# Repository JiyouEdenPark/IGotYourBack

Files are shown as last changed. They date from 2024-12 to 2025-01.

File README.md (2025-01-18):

# IGotYourBack

A mechanical recreation of a childhood game – where friends would write messages on your back and you had to focus on the feeling to get it right.

## Project Showcase
Project Demo (https://www.youtube.com/watch?v=ZsXyqrq_RdM)

## Description
In this day and age where we are inundated by ubiquitous and instantaneous communication, we invite you to an experience where you communicate with others word by word, one letter at a time. As the user gauges how keenly they can decipher a tactile message, it symbolizes how even the smallest units of communication can be misunderstood and highlights the amount of focus needed to comprehend someone else's intentions. If you have faith and 'lean into' the experience, there's a higher chance you will fare better at getting the message right. We got your back!

## Hardware

### Components
- Arduino Nano BLE (33 IoT) x1
- [MG996R Digital Servo Motor](https://www.amazon.com/diymore-6-Pack-MG996R-Digital-Helicopter/dp/B0CGRP59HJ) x3
  - Operating Voltage: 4.8V-7.2V
  - Stall Torque: 9.4kg/cm (4.8V), 11kg/cm (6V)
  - Speed: 0.17sec/60° (4.8V), 0.14sec/60° (6V)
- SG-5010 Servo Motor x3
  - Operating Voltage: 4.8V-6V
  - Stall Torque: 5.5kg/cm (4.8V), 6.5kg/cm (6V)
  - Speed: 0.16sec/60° (4.8V)
- [Hall Effect Sensor](https://www.digikey.com/en/products/detail/allegro-microsystems/A1324LUA-T/2728144?gQT=1) x1
  - Operating Voltage: 3.3V-5V
  - Digital Output
- Neodymium Magnet x1
  - N52 Grade
  - For switch activation
- Capacitors
  - 220μF Electrolytic Capacitor x3
  - 470μF Electrolytic Capacitor x3
- Wires
  - Solid Core Wire for circuit connections
  - Stranded Wire for servo extensions
- [Switching Power Supply](https://www.circuitspecialists.com/csi3005sm)
  - Output: 0-30V DC, 0-5A
  - Recommended setting: 5V/2A
- [ROT3U 6DOF Robot Arm](https://www.amazon.com/diymore-Aluminium-Mechanical-Robotic-Unassembled/dp/B0CJ4WR949) x1
  - Aluminum frame structure
  - Modified for project requirements
- Indicator Body
  - Based on [this model](https://www.youtube.com/watch?v=YqrbWCVa3xA)
  - Modified version used as initial prototype

### 3D Printed Parts 
- Robot Arm Extend Body
- Robot Arm Extend Pen

You can find the STL files in the `RobotArmStl` directory.

<!-- ### Circuit Diagram -->
<!-- [Circuit diagram will be added here] -->

## Wiring

Connect the components together in the following order:

| Arduino Pin | Component | Connection Type |
|---|---|---|
| Pin 2 | Hall Effect Sensor | Switch Input |
| Pin 3 | MG996R Servo | X-Axis Motor |
| Pin 5 | MG996R Servo | Y-Axis Motor |
| Pin 9 | MG996R Servo | Z-Axis Motor |
| Pin 15 | SG-5010 Servo | State Flag Motor |
| VIN | Hall Effect Sensor | VIN |
| VIN | MG996R Servo (X-Axis) | VIN |
| VIN | MG996R Servo (Y-Axis) | VIN |
| VIN | MG996R Servo (Z-Axis) | VIN |
| VIN | SG-5010 Servo | VIN |
| VIN | Power Supply | 5V/2A Input |
| GND | Hall Effect Sensor | Ground |
| GND | MG996R Servo (X-Axis) | Ground |
| GND | MG996R Servo (Y-Axis) | Ground |
| GND | MG996R Servo (Z-Axis) | Ground |
| GND | SG-5010 Servo | Ground |
| GND | Power Supply | Ground |

Notes:
- Each servo motor requires:
  - One 220μF capacitor for noise reduction
- Power supply input requires:
  - Three 470μF capacitors for power stabilization
- Use solid core wire for circuit connections
- Use stranded wire for servo extensions

## Contributors
- Jiyou Park
- Jinhee Shim
- Seungyun Yang

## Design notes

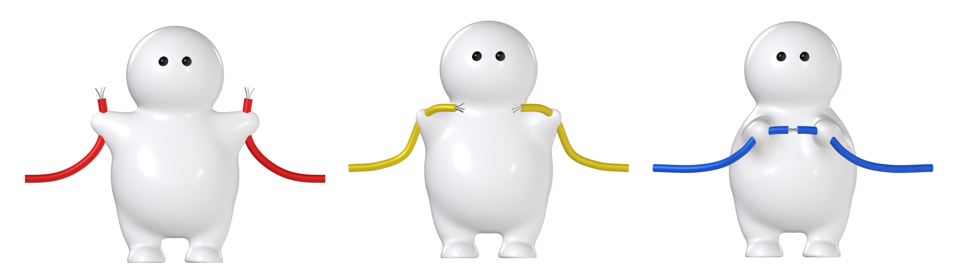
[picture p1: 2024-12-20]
P5/goodbye.png

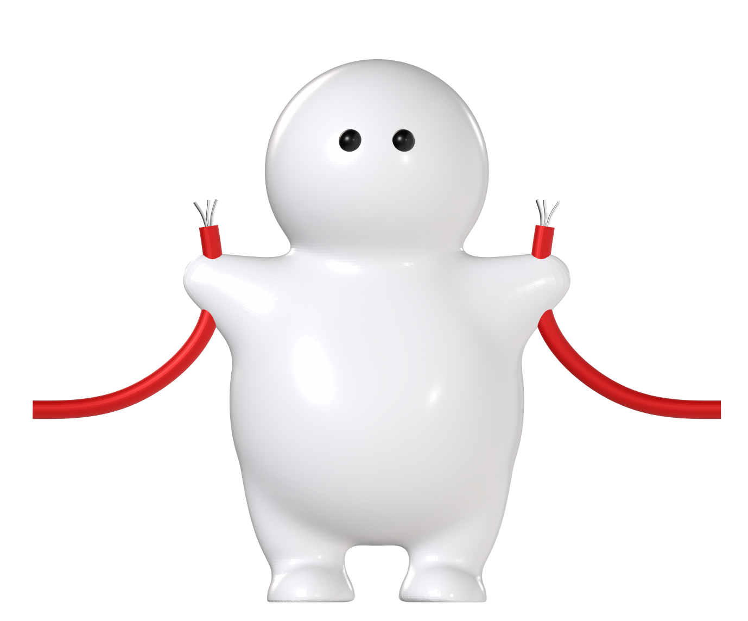
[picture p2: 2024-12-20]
P5/fun.png

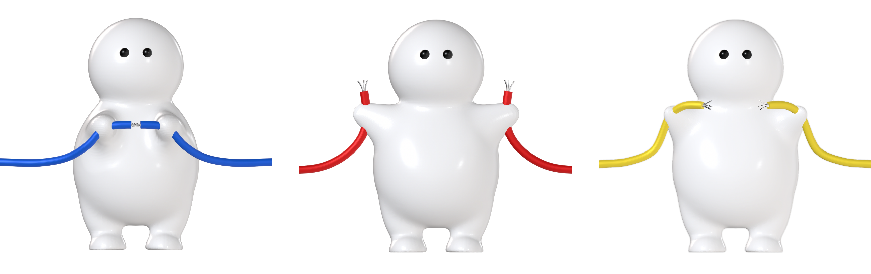
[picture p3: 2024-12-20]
P5/goodbye_2.png

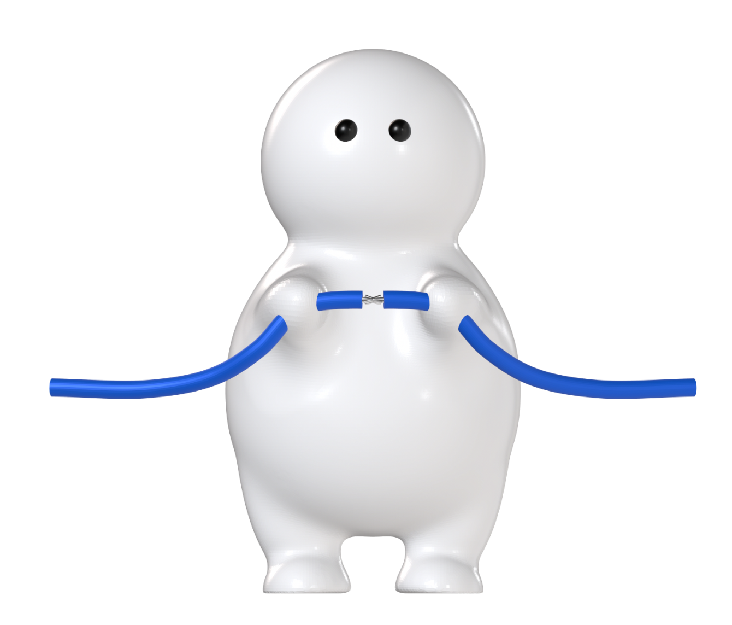
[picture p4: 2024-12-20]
P5/perfect.png

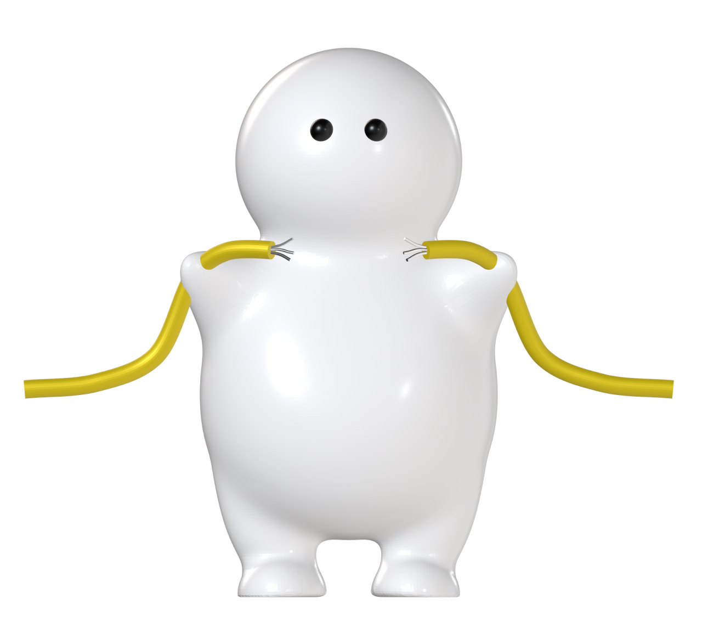
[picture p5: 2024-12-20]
P5/almost.png

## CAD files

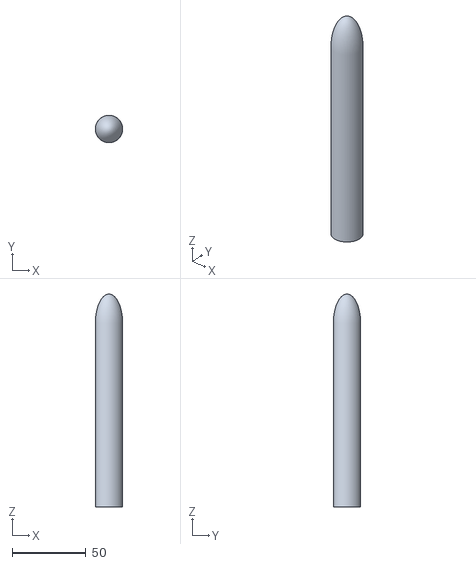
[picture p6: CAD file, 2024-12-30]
robotArmStl/robotArm_extend_pen.stl
18.6 x 18.6 x 144.9

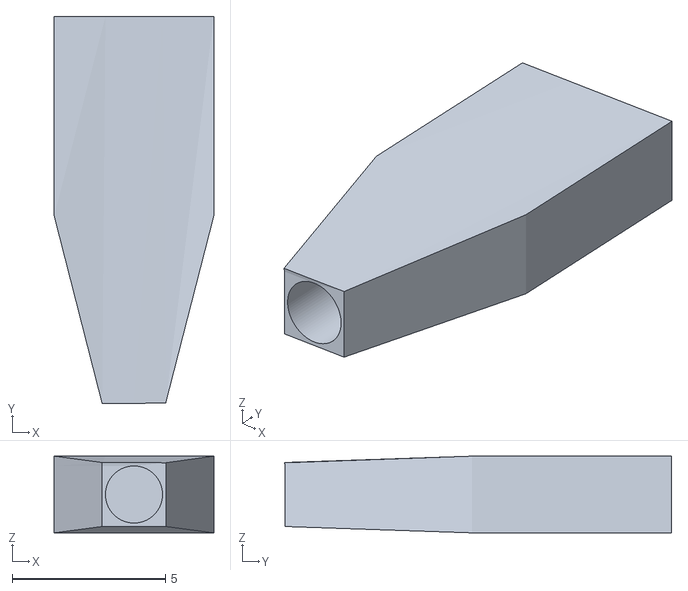
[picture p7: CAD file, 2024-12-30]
robotArmStl/robotArm_extend_body.stl
5.20 x 12.6 x 2.50

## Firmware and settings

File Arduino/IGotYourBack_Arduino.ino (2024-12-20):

#include <Arduino.h>
#include "ServoEasing.hpp"

//pin setup 
const int switchPin = 2;     // switch(buckle) pin
const int servoPin_x = 3;    // servo pin for robot arm motor x 
const int servoPin_y = 5;    // servo pin for robot arm motor y
const int servoPin_z = 9;    // servo pin for robot arm motor z
const int stateFlagPin = 15;    // servo pin for state flag motor    

//initiator switch state
bool switchState = false;

//states of the unit -- initialized to waiting stte
bool state_chair_waiting = true; // chair has string to print and waiting for user == vacant 
bool state_chair_printing = false; // chair is printing
bool state_monitor = false; // user is guessing / leaving input for the next person 

//string to print 
String print_string = "HELLO"; // initialized to "HELLO"

// Servo objects
ServoEasing servo_x_axis;
ServoEasing servo_y_axis;
ServoEasing servo_z_axis;
ServoEasing servo_flag; // servo for state flag

// Servo initial speed
int general_speed = 38;
int flag_speed = 50;

// Predefined commands for letters
float letter_A_commands[][3] = {
  {150, 70, 140},{112.5, 57.5, 120},{95, 40, 80},{77.5, 57.5, 115},{45, 70, 140},{45, 90, 140},{112.5, 57.5, 120},{77.5, 57.5, 115},{77.5, 77.5, 115}
};
float letter_B_commands[][3] = {
  {115, 35, 70},{125, 55, 110},{150, 70, 140},{150, 90, 140},{115, 35, 70},{95, 40, 80},{81.3, 50, 100},{95, 60, 120},{125, 55, 110},{95, 60, 120},{72.5, 63.8, 130},{95, 70, 150},{150, 70, 140},{150, 90, 140}
};
float letter_C_commands[][3] = {
  {70, 47.5, 95},{95, 40, 80},{120, 47.5, 95},{135, 62.5, 125},{95, 70, 150},{60, 62.5, 125},{60, 82.5, 125}
};
float letter_D_commands[][3] = {
  {115, 35, 70},{125, 55, 110},{150, 70, 140},{150, 90, 140},{115, 35, 70},{95, 40, 80},{81.3, 50, 100},{72.5, 63.8, 130},{95, 70, 150},{150, 70, 140},{150, 90, 140}
};
float letter_E_commands[][3] = {
  {115, 35, 70},{95, 40, 80},{75, 35, 70},{75, 55, 70},{125, 55, 110},{95, 60, 120},{65, 55, 110},{65, 75, 110},{115, 35, 70},{125, 55, 110},{150, 70, 140},{95, 70, 150},{45, 70, 140},{45, 90, 140}
};
float letter_F_commands[][3] = {
  {75, 35, 70},{95, 40, 80},{115, 35, 70},{125, 55, 110},{150, 70, 140},{150, 90, 140},{125, 55, 110},{95, 60, 120},{65, 55, 110},{65, 75, 110}
};
float letter_G_commands[][3] = {
  {85, 37.5, 75},{105, 37.5, 75},{120, 47.5, 95},{135, 62.5, 125},{130, 70, 145},{60, 70, 145},{65, 55, 110},{65, 75, 110},{95, 60, 120},{65, 55, 110},{65, 75, 110}
};
float letter_H_commands[][3] = {
  {115, 35, 70},{125, 55, 110},{150, 70, 140},{150, 90, 140},{125, 55, 110},{95, 60, 120},{65, 55, 110},{65, 75, 110},{75, 35, 70},{65, 55, 110},{45, 70, 140},{45, 90, 140}
};
float letter_I_commands[][3] = {
  {115, 35, 70},{95, 40, 80},{75, 35, 70},{75, 55, 70},{95, 40, 80},{95, 60, 120},{95, 70, 150},{95, 90, 150},{150, 70, 140},{95, 70, 150},{45, 70, 140},{45, 90, 140}
};
float letter_J_commands[][3] = {
  {115, 35, 70},{95, 40, 80},{75, 35, 70},{75, 55, 70},{95, 40, 80},{95, 60, 120},{95, 65, 135},{130, 70, 145},{135, 62.5, 125},{135, 82.5, 125}
};
float letter_K_commands[][3] = {
  {115, 35, 70},{125, 55, 110},{150, 70, 140},{150, 90, 140},{85, 37.5, 75},{95, 52.5, 100},{112.5, 57.5, 120},{95, 65, 135},{60, 70, 145},{60, 90, 145}
};
float letter_L_commands[][3] = {
  {115, 35, 70},{125, 55, 110},{150, 70, 140},{95, 70, 150},{45, 70, 140},{45, 90, 140}
};
float letter_M_commands[][3] = {
  {115, 35, 70},{125, 55, 110},{150, 70, 140},{150, 90, 140},{115, 35, 70},{108.8, 50, 100},{95, 60, 120},{81.3, 50, 100},{75, 35, 70},{65, 55, 110},{45, 70, 140},{45, 90, 140}
};
float letter_N_commands[][3] = {
  {115, 35, 70},{125, 55, 110},{150, 70, 140},{150, 90, 140},{115, 35, 70},{108.8, 50, 100},{95, 60, 120},{72.5, 63.8, 130},{45, 70, 140},{65, 55, 110},{75, 35, 70},{75, 55, 70}
};
float letter_O_commands[][3] = {
  {95, 40, 80},{105, 37.5, 75},{120, 47.5, 95},{135, 62.5, 125},{130, 70, 145},{60, 70, 145},{60, 62.5, 125},{70, 47.5, 95},{85, 37.5, 75},{85, 57.5, 75}
};
float letter_P_commands[][3] = {
  {115, 35, 70},{125, 55, 110},{150, 70, 140},{150, 90, 140},{115, 35, 70},{95, 40, 80},{81.3, 50, 100},{95, 60, 120},{125, 55, 110},{125, 75, 110}
};
float letter_Q_commands[][3] = {
  {95, 40, 80},{105, 37.5, 75},{120, 47.5, 95},{135, 62.5, 125},{130, 70, 145},{60, 70, 145},{60, 62.5, 125},{70, 47.5, 95},{85, 37.5, 75},{85, 57.5, 75},{95, 60, 120},{72.5, 63.8, 130},{45, 70, 140},{45, 90, 140}
};
float letter_R_commands[][3] = {
  {115, 35, 70},{125, 55, 110},{150, 70, 140},{150, 90, 140},{115, 35, 70},{95, 40, 80},{81.3, 50, 100},{95, 60, 120},{125, 55, 110},{112.5, 57.5, 120},{95, 65, 135},{60, 70, 145},{60, 90, 145}
};
float letter_S_commands[][3] = {
  {85, 37.5, 75},{105, 37.5, 75},{120, 47.5, 95},{112.5, 57.5, 120},{77.5, 57.5, 115},{60, 62.5, 125},{60, 70, 145},{130, 70, 145},{130, 90, 145}
};
float letter_T_commands[][3] = {
  {115, 35, 70},{95, 40, 80},{75, 35, 70},{75, 55, 70},{95, 40, 80},{95, 60, 120},{95, 70, 150},{95, 90, 150}
};
float letter_U_commands[][3] = {
  {115, 35, 70},{125, 55, 110},{130, 70, 145},{60, 70, 145},{65, 55, 110},{75, 35, 70},{75, 55, 70}
};
float letter_V_commands[][3] = {
  {115, 35, 70},{112.5, 57.5, 120},{95, 70, 150},{77.5, 57.5, 115},{75, 35, 70},{75, 55, 70}
};
float letter_W_commands[][3] = {
  {115, 35, 70},{125, 55, 110},{130, 70, 145},{95, 60, 120},{95, 52.5, 100},{95, 60, 120},{60, 70, 145},{65, 55, 110},{75, 35, 70},{75, 55, 70}
};
float letter_X_commands[][3] = {
  {115, 35, 70},{108.8, 50, 100},{95, 60, 120},{72.5, 63.8, 130},{45, 70, 140},{45, 90, 140},{75, 35, 70},{81.3, 50, 100},{95, 60, 120},{117.5, 63.8, 130},{150, 70, 140},{150, 90, 140}
};
float letter_Y_commands[][3] = {
  {115, 35, 70},{108.8, 50, 100},{108.8, 70, 100},{75, 35, 70},{81.3, 50, 100},{95, 60, 120},{95, 70, 150},{95, 90, 150}
};
float letter_Z_commands[][3] = {
  {115, 35, 70},{95, 40, 80},{75, 35, 70},{81.3, 50, 100},{95, 60, 120},{117.5, 63.8, 130},{150, 70, 140},{95, 70, 150},{45, 70, 140},{45, 90, 140}
};
float period_commands[][3] = {
  {45, 90, 140},{45, 70, 140},{45, 90, 140}
};

// Struct for letter definitions
struct Letter {
  char letter;
  float (*commands)[3];
  int numCommands;
};

// Define supported letters
Letter letterCommands[] = {
  {'A', letter_A_commands, sizeof(letter_A_commands) / sizeof(letter_A_commands[0])},
  {'B', letter_B_commands, sizeof(letter_B_commands) / sizeof(letter_B_commands[0])},
  {'C', letter_C_commands, sizeof(letter_C_commands) / sizeof(letter_C_commands[0])},
  {'D', letter_D_commands, sizeof(letter_D_commands) / sizeof(letter_D_commands[0])},
  {'E', letter_E_commands, sizeof(letter_E_commands) / sizeof(letter_E_commands[0])},
  {'F', letter_F_commands, sizeof(letter_F_commands) / sizeof(letter_F_commands[0])},
  {'G', letter_G_commands, sizeof(letter_G_commands) / sizeof(letter_G_commands[0])},
  {'H', letter_H_commands, sizeof(letter_H_commands) / sizeof(letter_H_commands[0])},
  {'I', letter_I_commands, sizeof(letter_I_commands) / sizeof(letter_I_commands[0])},
  {'J', letter_J_commands, sizeof(letter_J_commands) / sizeof(letter_J_commands[0])},
  {'K', letter_K_commands, sizeof(letter_K_commands) / sizeof(letter_K_commands[0])},
  {'L', letter_L_commands, sizeof(letter_L_commands) / sizeof(letter_L_commands[0])},
  {'M', letter_M_commands, sizeof(letter_M_commands) / sizeof(letter_M_commands[0])},
  {'N', letter_N_commands, sizeof(letter_N_commands) / sizeof(letter_N_commands[0])},
  {'O', letter_O_commands, sizeof(letter_O_commands) / sizeof(letter_O_commands[0])},
  {'P', letter_P_commands, sizeof(letter_P_commands) / sizeof(letter_P_commands[0])},
  {'Q', letter_Q_commands, sizeof(letter_Q_commands) / sizeof(letter_Q_commands[0])},
  {'R', letter_R_commands, sizeof(letter_R_commands) / sizeof(letter_R_commands[0])},
  {'S', letter_S_commands, sizeof(letter_S_commands) / sizeof(letter_S_commands[0])},
  {'T', letter_T_commands, sizeof(letter_T_commands) / sizeof(letter_T_commands[0])},
  {'U', letter_U_commands, sizeof(letter_U_commands) / sizeof(letter_U_commands[0])},
  {'V', letter_V_commands, sizeof(letter_V_commands) / sizeof(letter_V_commands[0])},
  {'W', letter_W_commands, sizeof(letter_W_commands) / sizeof(letter_W_commands[0])},
  {'X', letter_X_commands, sizeof(letter_X_commands) / sizeof(letter_X_commands[0])},
  {'Y', letter_Y_commands, sizeof(letter_Y_commands) / sizeof(letter_Y_commands[0])},
  {'Z', letter_Z_commands, sizeof(letter_Z_commands) / sizeof(letter_Z_commands[0])},
  {'period', period_commands, sizeof(period_commands) / sizeof(period_commands[0])}
};

void setup() {
  // setup serial 
  Serial.begin(9600);
  while (Serial.available() <= 0) {
    Serial.println("hello"); // send a starting message
    delay(300);              // wait 1/3 second
  }

  // initial positions for the robot arm servos
  servo_x_axis.attach(servoPin_x, 95); // pin 및 시작 X축 각도
  servo_y_axis.attach(servoPin_y, 65); // pin 및 시작 Y축 각도
  servo_z_axis.attach(servoPin_z, 80); // pin 및 시작 Z축 각도

  // initial position for the state flag servo (vacant)
  servo_flag.attach(stateFlagPin, 100); // vacant

  // Servo speed and easing
  setSpeedForAllServos(general_speed);
  setEasingTypeForAllServos(EASE_SINE_IN_OUT);

  delay(500); // 시작 위치로 이동 대기
}

void loop() {
  // read from Hall Effect sensor 
  int sensorValue = digitalRead(switchPin);

  // update switch state
  if(sensorValue == LOW) { 
    switchState = true;
  } else {
    switchState = false;
  }
  
  //if the state is in waiting and the initiator switch changes to true, then change state to printing
  if(state_chair_waiting && switchState) {
    state_chair_waiting = false;
    state_chair_printing = true;
    
    //show 'occupied' on state flag
    changeStateFlag(state_chair_waiting);
  }
  
  //if the state is in printing and switch is still on, write word
  if(state_chair_printing) {
    while(switchState){
      delay(2000); //wait 2 seconds and then start writing
      writeWord(print_string);
      delay(5000); // delay for 5 seconds while user decides whether to try again
      
      // check Hall Effect sensor
      sensorValue = digitalRead(switchPin);
      if(sensorValue == LOW) { 
        switchState = true;
      } else {
        switchState = false;
      }
    }
    
    //after the word is done writing, change states and send Serial 
    state_chair_printing = false;
    state_monitor = true;
    Serial.println(print_string);
  }

  if (Serial.available() > 0) {
    //read input from serial
    String inString = Serial.readStringUntil('\n'); // Reads until newline character

    //if the string isn't the start signal(11111) and it is in monitor state then store the string to be printed with the robot arm and change states to waiting 
    //if (inString != "11111" && state_monitor) {
    if (state_monitor) {
      print_string = inString;
      state_monitor = false;
      state_chair_waiting = true;
    }
  }
  //show 'vacant' on state flag
  changeStateFlag(state_chair_waiting);
}

// function that splits string into letters and calls writeLetter()
void writeWord(String word) {
  //write each letter
  for (size_t i = 0; i < word.length(); i++) {
    char letter = word[i];
    writeLetter(letter);
  }

  //write a period
  Letter* periodd = findLetter('period');

  // Execute each servo command for the letter
  for (int i = 0; i < periodd->numCommands; i++) {
    float x_angle = periodd->commands[i][0];
    float y_angle = periodd->commands[i][1];
    float z_angle = periodd->commands[i][2];

    servo_x_axis.setEaseTo(x_angle, general_speed);
    servo_y_axis.setEaseTo(y_angle, general_speed);
    servo_z_axis.setEaseTo(z_angle, general_speed);

    synchronizeAllServosStartAndWaitForAllServosToStop();
    delay(200); // Adjust delay as needed
  }
}

// function that writes a single letter by executing its predefined servo commands
void writeLetter(char letter) {
  Letter* letterData = findLetter(letter);

  if (letterData) {
    // Execute each servo command for the letter
    for (int i = 0; i < letterData->numCommands; i++) {
      float x_angle = letterData->commands[i][0];
      float y_angle = letterData->commands[i][1];
      float z_angle = letterData->commands[i][2];

      servo_x_axis.setEaseTo(x_angle, general_speed);
      servo_y_axis.setEaseTo(y_angle, general_speed);
      servo_z_axis.setEaseTo(z_angle, general_speed);

      synchronizeAllServosStartAndWaitForAllServosToStop();
      delay(200); // Adjust delay as needed
    }
  } 
}

// Find the letter's command data
Letter* findLetter(char letter) {
  for (int i = 0; i < sizeof(letterCommands) / sizeof(letterCommands[0]); i++) {
    if (letterCommands[i].letter == letter) {
      return &letterCommands[i];
    }
  }
  return nullptr; // Return null if the letter is not supported
}


// function that changes state flag servo 
void changeStateFlag(bool waitingState) {
  if (waitingState) { 
    servo_flag.setEaseTo(100, flag_speed); // when in waiting set target position to 100
  } else { 
    servo_flag.setEaseTo(20, flag_speed); // when in using set target position to 20
  }
  synchronizeAllServosStartAndWaitForAllServosToStop();
}

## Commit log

2024-12-20 Add Arduino code
2024-12-20 Move Arduino folder
2024-12-30 Create STL folder
2025-01-17 Add Wirings
